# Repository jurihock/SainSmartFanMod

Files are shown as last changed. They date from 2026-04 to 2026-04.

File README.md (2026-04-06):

# SainSmart solder fume extractor modification

This project is about replacing the default AC fan in the [SainSmart solder fume extractor](https://www.sainsmart.com/products/sainsmart-solder-smoke-absorber-remover-fume-extractor-for-soldering) with a DC fan like [Noctua NF-A14](https://www.noctua.at/en/products/nf-a14-industrialppc-3000-pwm).

## Why?

- the built-in fan is way too loud
- it runs at constant speed only
- the power cable is way too stiff

## Features

- toggle switch to power the device on or off integrated in the housing
- dual LED to indicate power on and standby
- MOSFET switch to turn the fan on or off using MCU
- pot with a large knob 🫠 to select the fan speed

## Thoughts

### Electrical

In fact, the Noctua fan draws around 2A during the initial turn. I decided to use a logic-level MOSFET to switch the fan on. Adding a cap between 10uF and 100uF increases the Miller effect, forcing the fan to start up slowly and reducing the initial current as well. But in this case, an NPN transistor is needed to ground the PWM signal against the N-MOSFET drain.

I'm unsure whether a DC fan requires a flyback diode. I decided to skip it for now.

### Mechanical

The JST connectors are intentionally placed on the edges, which puts mechanical stress on the board. There is certainly a better solution for connector placement.

## How it looks like

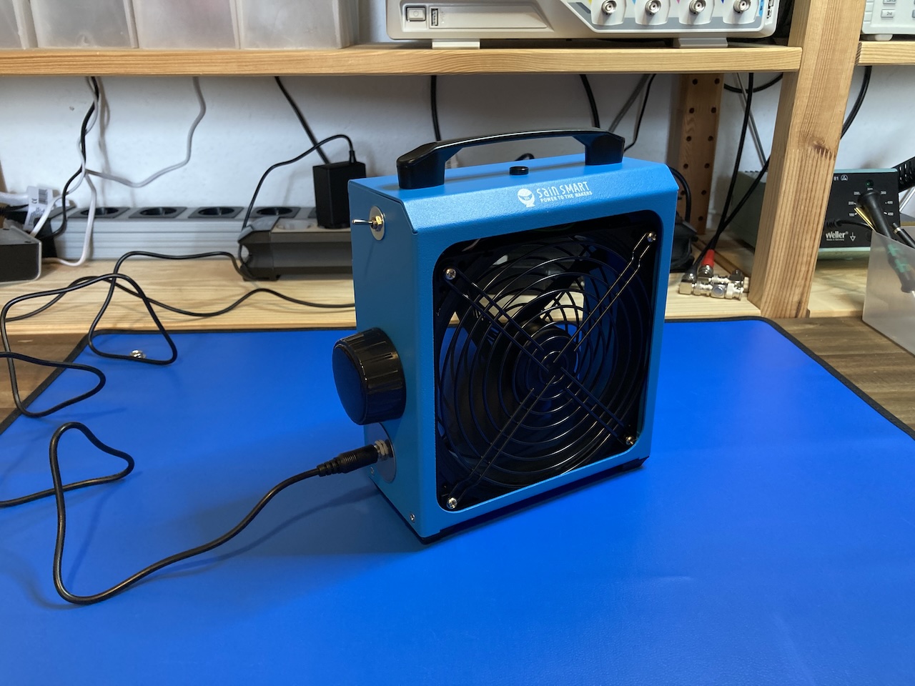
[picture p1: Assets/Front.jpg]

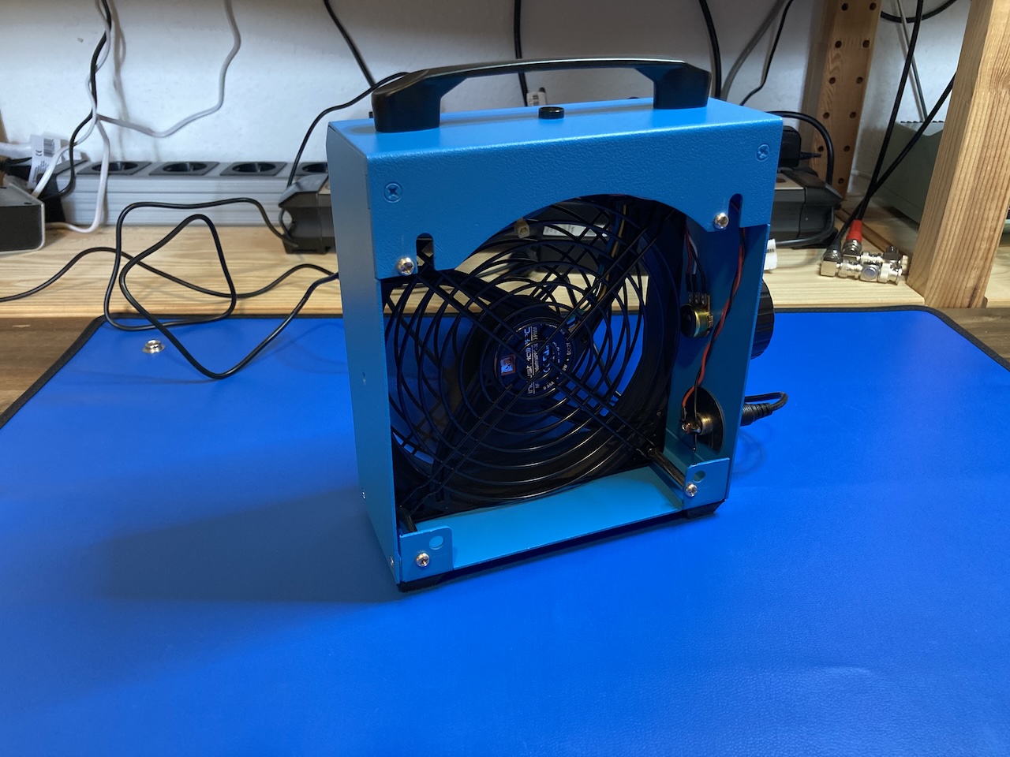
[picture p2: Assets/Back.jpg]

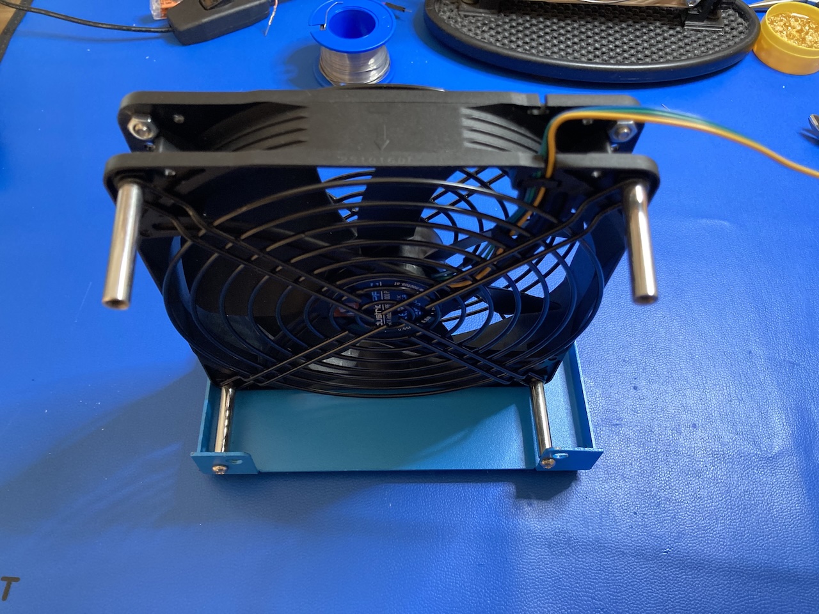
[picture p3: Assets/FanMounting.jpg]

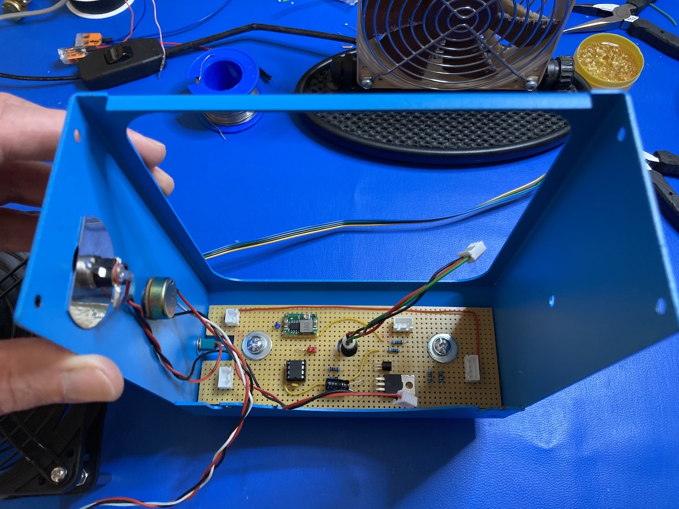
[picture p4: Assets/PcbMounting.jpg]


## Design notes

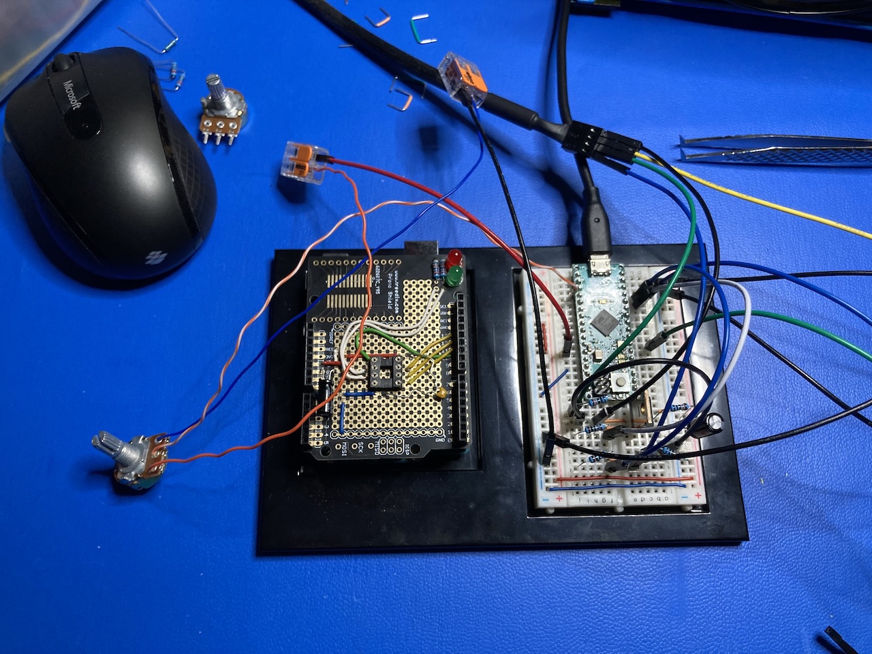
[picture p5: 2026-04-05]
Assets/Prototype.jpg

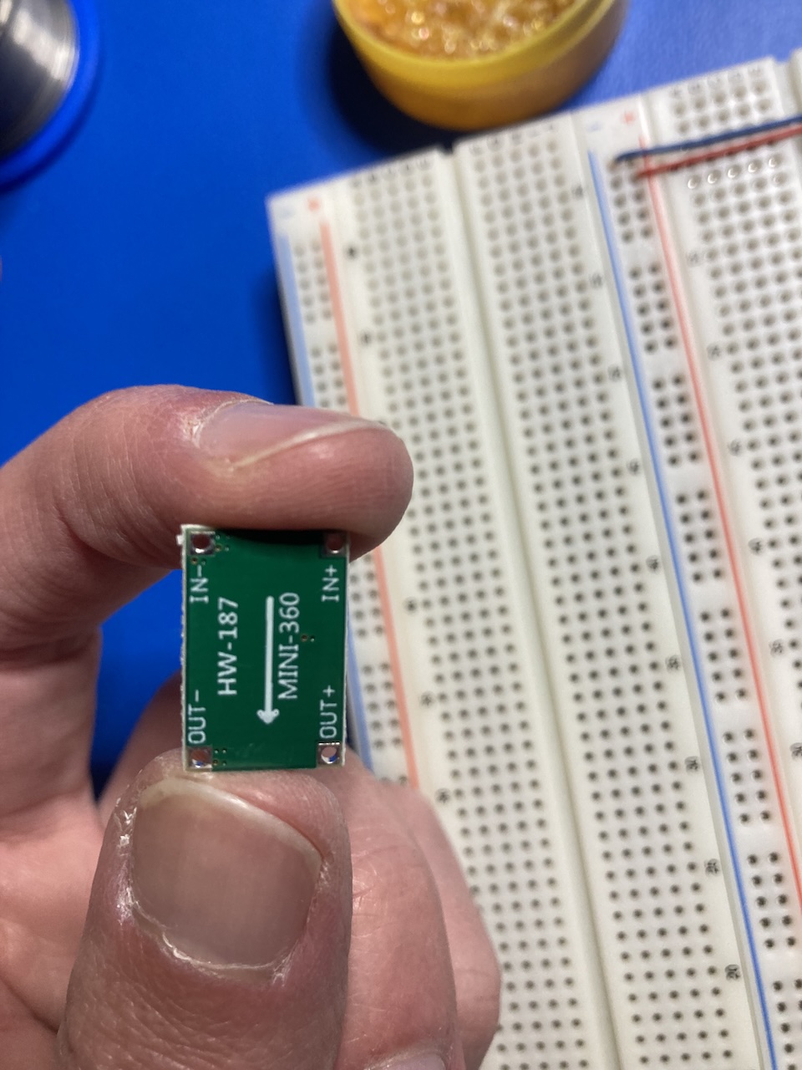
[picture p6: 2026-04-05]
Assets/Buck.jpg

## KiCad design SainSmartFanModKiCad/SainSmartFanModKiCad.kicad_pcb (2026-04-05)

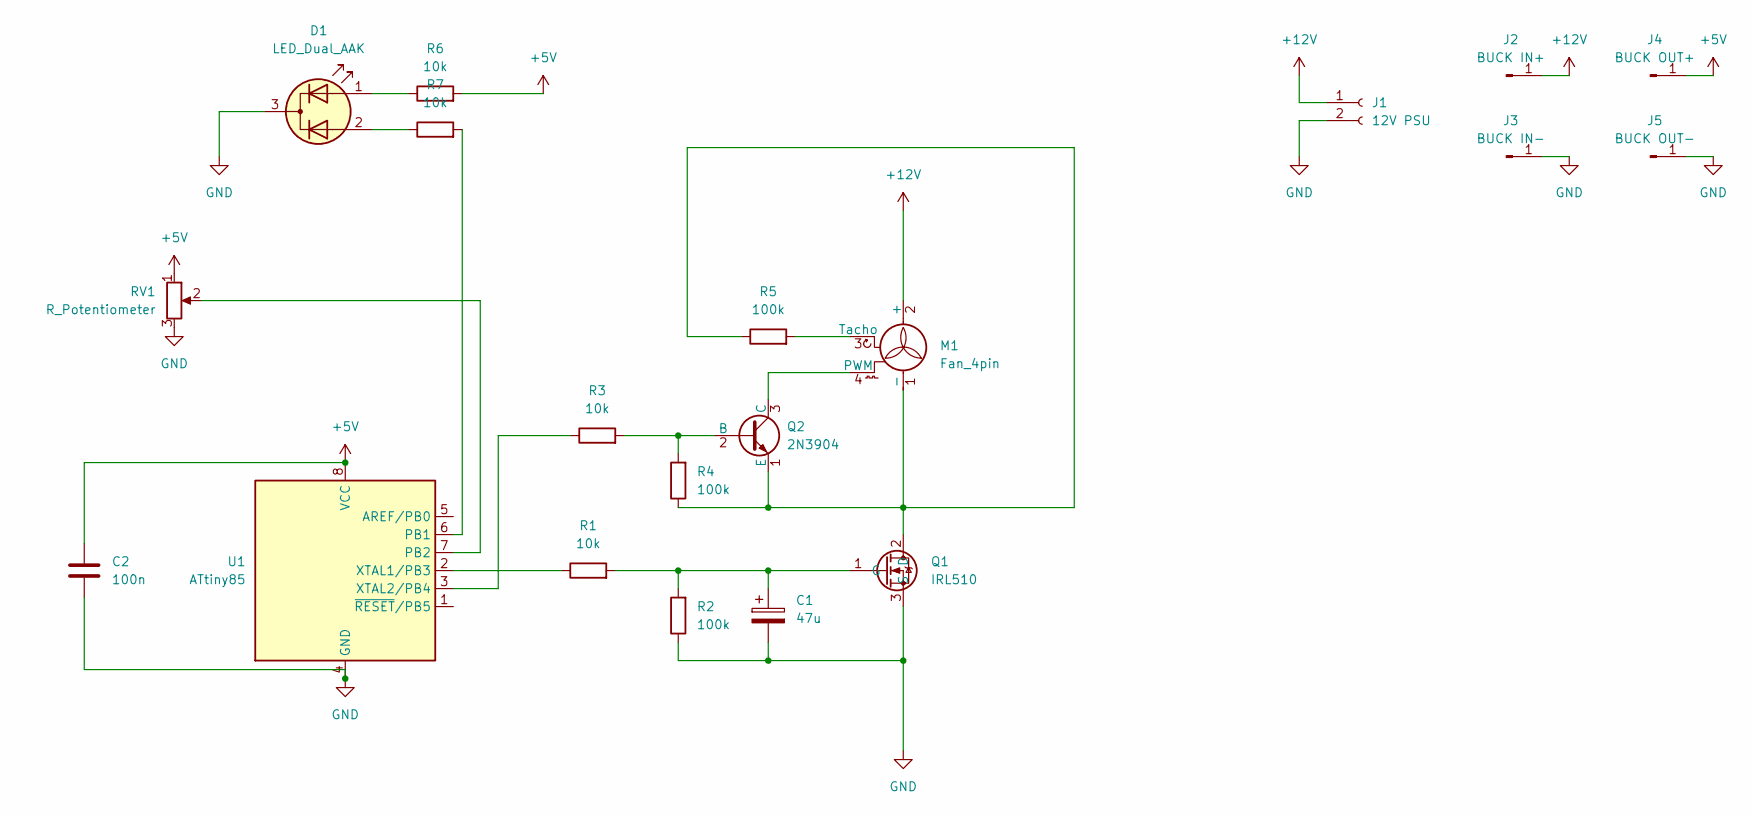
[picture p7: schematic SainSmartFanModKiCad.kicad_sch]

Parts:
C1: 47u; CP_Radial_D6.3mm_P2.50mm
C2: 100n; C_Disc_D3.0mm_W2.0mm_P2.50mm
D1: LED_Dual_AAK; JST_EH_B3B-EH-A_1x03_P2.50mm_Vertical
J1: 12V PSU; JST_EH_B2B-EH-A_1x02_P2.50mm_Vertical
J2: BUCK IN+; PinHeader_1x01_P1.00mm_Vertical
J3: BUCK IN-; PinHeader_1x01_P1.00mm_Vertical
J4: BUCK OUT+; PinHeader_1x01_P1.00mm_Vertical
J5: BUCK OUT-; PinHeader_1x01_P1.00mm_Vertical
M1: Fan_4pin; JST_EH_B4B-EH-A_1x04_P2.50mm_Vertical
Q1: IRL510; TO-220-3_Vertical
Q2: 2N3904; TO-92_Inline_Wide
R1, R3, R6, R7: 10k; R_Axial_DIN0207_L6.3mm_D2.5mm_P10.16mm_Horizontal
R2, R4, R5: 100k; R_Axial_DIN0207_L6.3mm_D2.5mm_P10.16mm_Horizontal
RV1: R_Potentiometer; JST_EH_B3B-EH-A_1x03_P2.50mm_Vertical
U1: ATtiny85; DIP-8_W7.62mm

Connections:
+5V: C2.1, J4.1, R6.2, RV1.1, U1.8 (VCC)
+12V: J1.1, J2.1, M1.2 (+)
GND: C1.2, C2.2, D1.3 (K), J1.2, J3.1, J5.1, Q1.3 (S), R2.1, RV1.3, U1.4 (GND)
unnamed: D1.1 (A1), R6.1
unnamed: D1.2 (A2), R7.1
unnamed: M1.1 (-), Q1.2 (D), Q2.1 (E), R4.1, R5.1
unnamed: M1.4 (PWM), Q2.3 (C)
unnamed: M1.3 (Tacho), R5.2
unnamed: C1.1, Q1.1 (G), R1.2, R2.2
unnamed: Q2.2 (B), R3.2, R4.2
unnamed: R7.2, U1.6 (PB1)
unnamed: RV1.2, U1.7 (PB2)
unnamed: R1.1, U1.2 (XTAL1/PB3)
unnamed: R3.1, U1.3 (XTAL2/PB4)

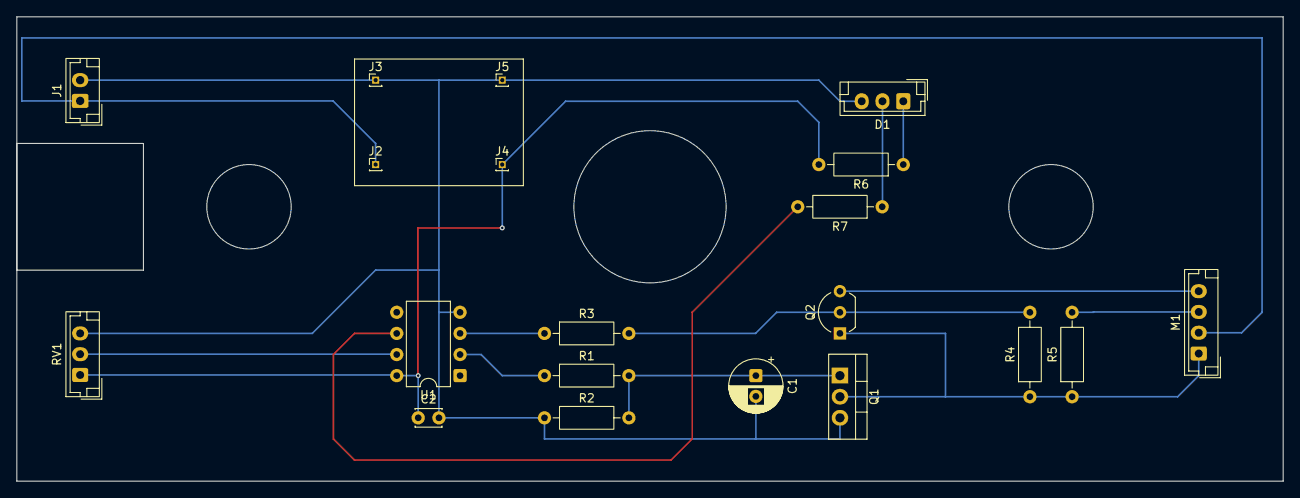
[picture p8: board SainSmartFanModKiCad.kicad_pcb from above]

Board: 2 copper layers, 152.4 x 55.9 mm, 20 parts (0 on the bottom side), 14 nets.

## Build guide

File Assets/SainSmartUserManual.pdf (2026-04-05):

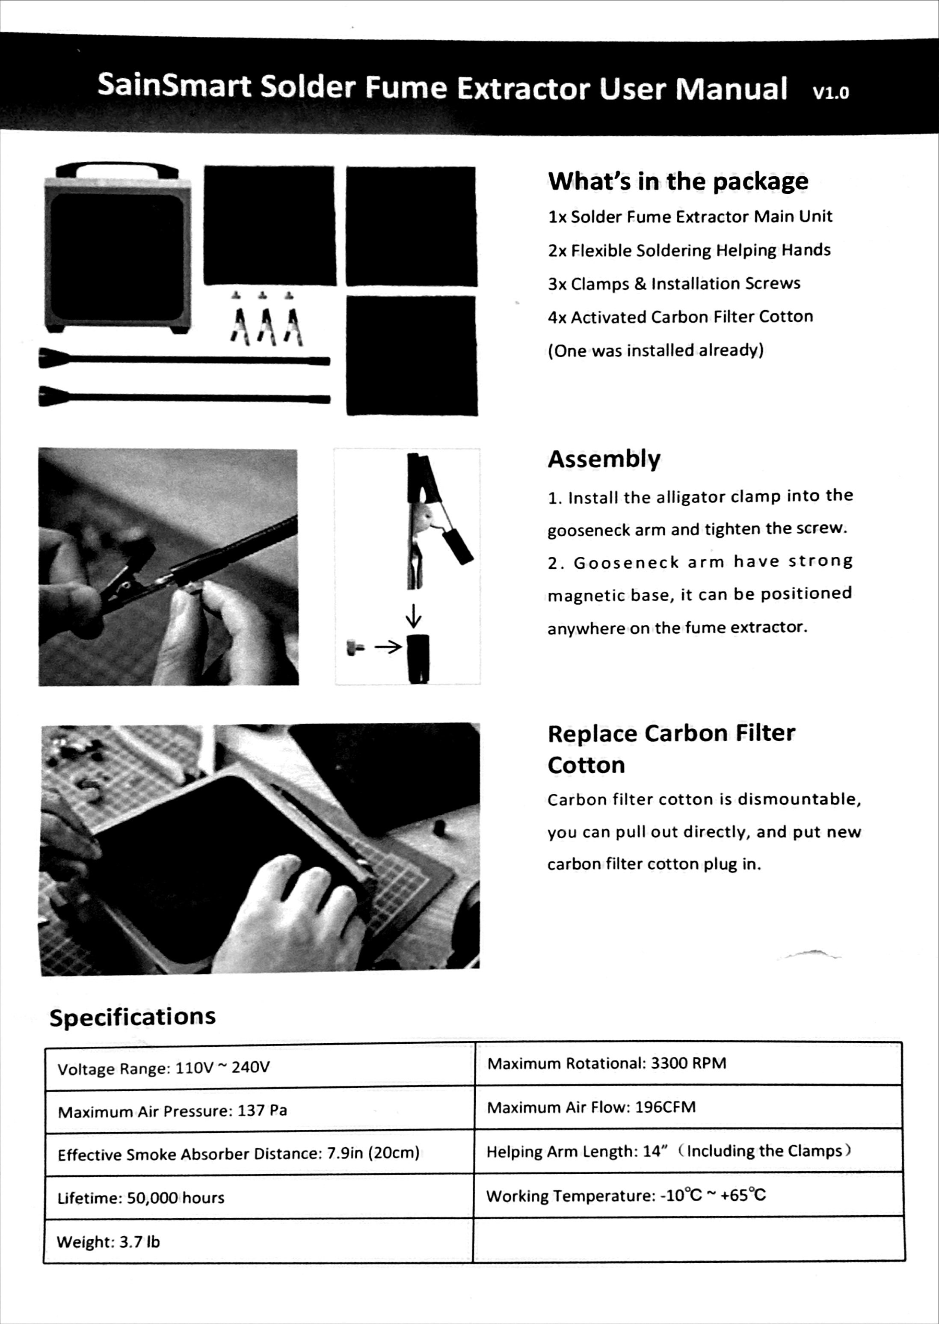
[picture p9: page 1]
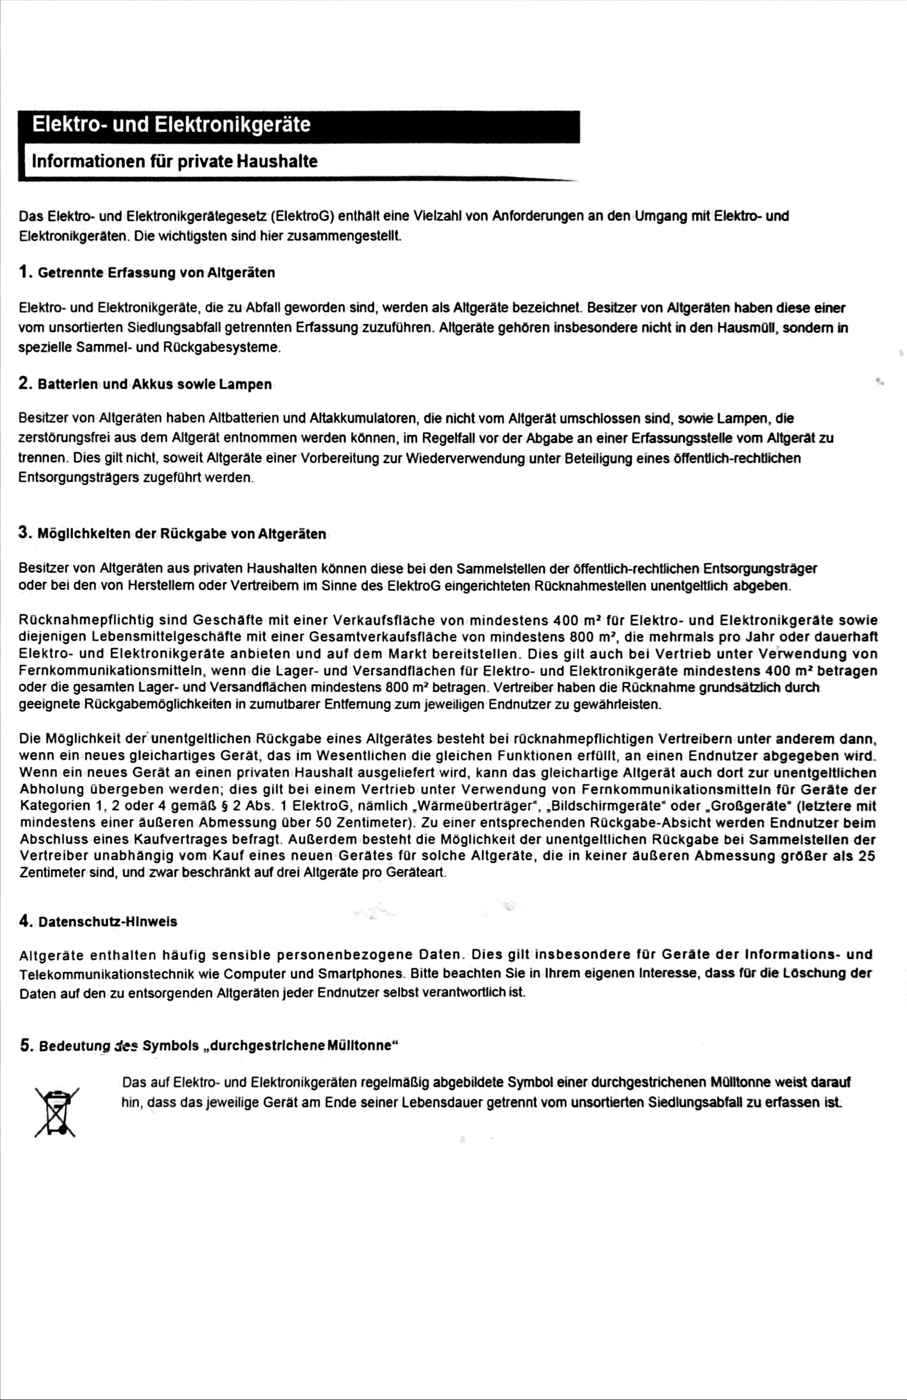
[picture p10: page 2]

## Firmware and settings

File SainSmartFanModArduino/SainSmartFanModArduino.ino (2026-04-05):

// ATtiny85:  ArduinoISP + ATTinyCore
// Clock:     8 MHz (internal)
// PWM:       25 kHz on PB4 (D4, OC1B) using Timer1 with PLL clock and /16 prescaler
// FAN:       PB3 (D3), MOSFET gate
// POT:       A1 (PB2)

const uint8_t FAN = 3;    // PB3 -> MOSFET gate (HIGH = ON)
const uint8_t PWM = 4;    // PB4 -> OC1B -> NPN base (sinks fan PWM, active-low at fan)
const uint8_t LED = 1;    // PB1
const uint8_t POT = A1;   // PB2
const uint8_t TOP = 159;  // Timer1 TOP for 25 kHz: f = (PLL 64MHz / 16) / (TOP+1) = 4MHz / 160 = 25kHz
const float   MIN = 0.2f; // min. duty cycle 20%

float getDuty()
{
  float duty = analogRead(POT) / 1023.0f;
  
  duty = powf(duty, 1.5f); // apply gamma
  duty = duty * (1.0f - MIN) + MIN; // scale to 20%..100%

  return duty;
}

void setDuty(float duty)
{
  duty = constrain(duty, 0.0f, 1.0f);
  duty = 1.0f - duty; // active-low at fan (NPN sink)

  uint16_t ticks = (uint16_t)((TOP + 1) * duty);

  if (ticks > 0)
  {
    ticks -= 1;
  }

  OCR1B = (uint8_t)ticks;
}

void setFan(bool state)
{
  if (state)
  {
    digitalWrite(LED, LOW);  // LED OFF
    pinMode(PWM, OUTPUT);
    GTCCR |= _BV(COM1B1);    // enable OC1B on pin (non-inverting)
    digitalWrite(FAN, HIGH); // MOSFET ON
    delay(1000);
  }
  else
  {
    digitalWrite(LED, HIGH); // LED ON
    digitalWrite(FAN, LOW);  // MOSFET OFF
    delay(1000);             // let it settle
    GTCCR &= ~_BV(COM1B1);   // disconnect OC1B from pin
    pinMode(PWM, INPUT);     // Hi-Z to avoid backfeed
  }
}

void setup()
{
  pinMode(FAN, OUTPUT);
  pinMode(PWM, OUTPUT);
  pinMode(LED, OUTPUT);

  // Enable PLL and route to Timer1
  PLLCSR = _BV(PLLE);                 // enable PLL
  delay(2);
  while (!(PLLCSR & _BV(PLOCK))) {}   // wait for lock
  PLLCSR |= _BV(PCKE);                // PLL clock to Timer1

  // Timer1 setup: Fast PWM, TOP = OCR1C, non-inverting on OC1B, prescaler = /16
  TCCR1 = 0;
  GTCCR = 0;

  // Prescaler /16 and PWM enable
  TCCR1 = _BV(PWM1A) | _BV(CS12) | _BV(CS10);  // CS1x = 0b0101 -> /16
  GTCCR = _BV(PWM1B) | _BV(COM1B1);            // enable OC1B, non-inverting

  OCR1C = TOP;     // sets 25 kHz
  OCR1B = 0;       // start at 0% (line high at fan)

  setFan(false);
}

void loop()
{
  static float oldDuty = MIN;
  static bool oldState = false;

  float newDuty = (getDuty() + oldDuty) / 2.0f;
  bool newState = oldState;

  // schmitt trigger around MIN
  float newDelta = newDuty - MIN;

  if (!newState && newDelta >= 0.03f)
  {
    // turn ON when duty ≥ MIN + 3%
    newState = true;
  }
  else if (newState && newDelta <= 0.01f)
  {
    // turn OFF when duty ≤ MIN + 1%
    newState = false;
  }

  if (newDuty != oldDuty)
  {
    setDuty(newDuty);
  }

  if (newState != oldState)
  {
    setFan(newState);
  }

  oldDuty = newDuty;
  oldState = newState;

  delay(100);
}

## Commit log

2026-04-05 Add sources
    [SainSmartFanModKiCad.kicad_pcb, SainSmartFanModKiCad.kicad_sch]
2026-04-05 Move files
    [SainSmartFanModKiCad.kicad_pcb, SainSmartFanModKiCad.kicad_sch]
2026-04-05 Enhance README with usage images and instructions
    Added images and section on how to use the device.
